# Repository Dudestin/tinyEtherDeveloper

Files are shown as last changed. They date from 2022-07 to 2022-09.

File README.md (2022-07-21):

View this project on [CADLAB.io](https://cadlab.io/project/25780). 
Contact : [@mozc_channel](https://twitter.com/mozc_channel)

# [WIP]tinyEtherDeveloper
Inexpensive FPGA board-based Ethernet evaluation board project.  
Consists mostly of DIP components and uses Tang PriMER. It can be built for about only $50.

## About
**7,000円程度**でほとんどの部品が秋葉原で揃う, Ethernetポートを**4つ**備えた実験ボードです. 10BASE-Tに対応しています.  
はんだ付けが苦手な方でも容易に実装できるよう, 極力面実装部品の仕様は控えています.  
FPGAボードには, SipeedのTang PriMERを用いており, そこそこ豊富なBRAMを備えるため, 様々な応用が可能です.

| Overview | Overview2 | PCB Layout |
| --- | --- |  --- |
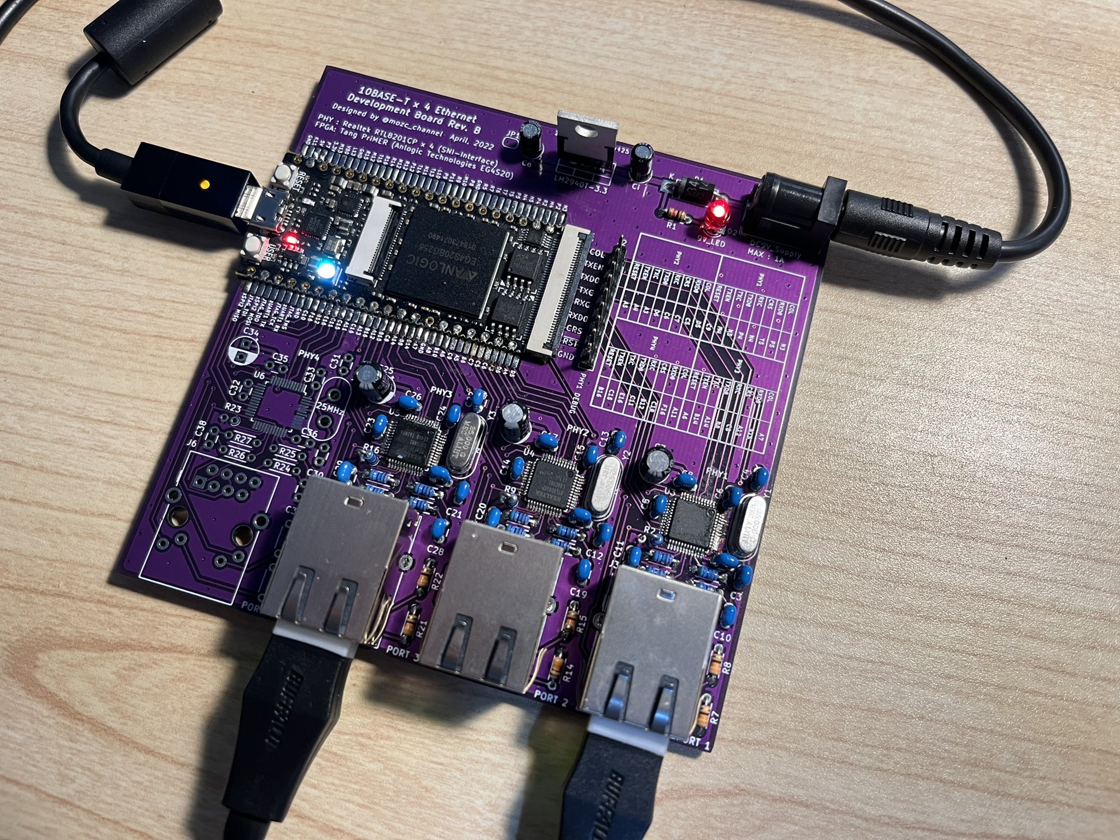
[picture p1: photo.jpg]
assembleBoard
|  |  | |
## Usages and Applications
- Repeater Hub
- Video Broadcasting (Use with MIPI Camera)
- NTP Server
- L2 Switch
- L3 Switch
- Hardware VPN router

## Where to get parts
[部品表](https://partscabi.net/list/92284b79-cc50-4855-a5a0-e0b6e620e11a), [RTL8201CP](https://jp.rs-online.com/web/p/ethernet-interface-ics/0419952) (PHYチップ)

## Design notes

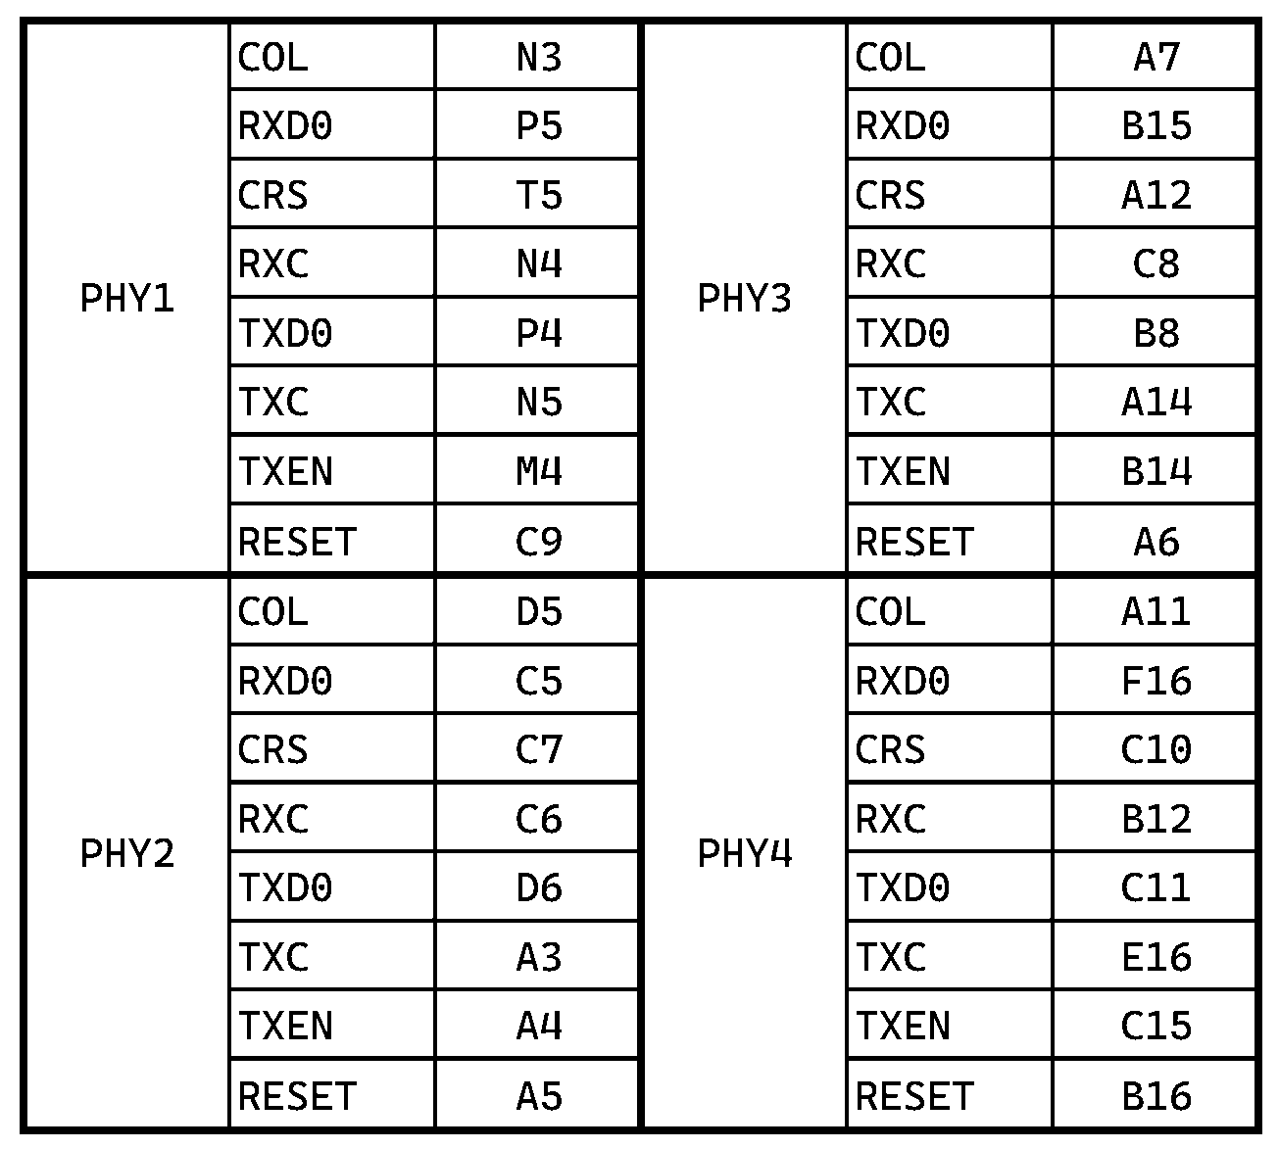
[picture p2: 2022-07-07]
PCB_project/pico_router/table.bmp

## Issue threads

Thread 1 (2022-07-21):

MACスイッチ (L2スイッチ) の実装案

Dudestin, 2022-07-21:
### 状態遷移図
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
#### `AWAIT`と`DESTROY`をどう使い分けるか
- マクロで`AWAIT`と`DESTROY`どちらをそれぞれの転送モードで有効にするか設定できるように.

Dudestin, 2022-07-21:
`MULTICAST`状態は不要
フラッディングさせよう

Dudestin, 2022-07-22:
`BROADCAST`状態も不要.
`UNICAST`状態も削除し`TX`状態とマージ.

Dudestin, 2022-07-22:
`DESTROY`状態も不要.
出力fifo設定信号になにも出力しなければよいだけ.

Dudestin, 2022-07-22:
`WAIT`は実装せず, 溢れたら破棄

Closed 2022-07-23.

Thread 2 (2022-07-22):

MACテーブルの実装方法

Dudestin, 2022-07-22:
## テーブル実装手法
CAM (Contents Associated Memory) を用いる. `data`に対応する`addr`を索引することができるが, `addr->data`が多対1の場合はそのままでは実装できない. したがって, 次のようにaddrを構成し多対1の索引を実現する.
```verilog
addr = {counter, PORT};
```
ここで, `counter`はポート毎に用意され, 新規MACが来る度にインクリメントされる. `PORT`はポート番号.
索引する際は`addr`の下位ビットをスライスすることでポート番号を特定する.
あるポートのMACテーブルがいっぱいの状態で新しいMACアドレスを挿入する際, `counter`のオーバーフローにより自動的に最古のデータが置き換わる.
ポート毎にストアできるMACアドレスの数はcounterの表現可能な数値である.
ブロードキャストアドレスはロジックで判別させる.
### CAMの仕様
`addr`のbit幅 : 5 (ポート毎に8つのMACアドレスを記憶可能)
2^5=32bit幅のメモリを要求する. 現実的なラインは6までか.

### MACテーブルのCAMを用いた実装の例.
| `addr` | `data` | 備考 |
| - | - | - |
| `{3'bxxx, 2'b00}` | `FF:FF:FF:FF:FF:FF` | ブロードキャストアドレス, ロジックで判別 |
| `{3'bxxx, 2'b01}` | `FF:FF:FF:FF:FF:FF` | ブロードキャストアドレス, ロジックで判別 |
| `{3'bxxx, 2'b10}` | `FF:FF:FF:FF:FF:FF` | ブロードキャストアドレス, ロジックで判別 |
| `{3'bxxx, 2'b11}` | `FF:FF:FF:FF:FF:FF` | ブロードキャストアドレス, ロジックで判別 |
| `{3'b000, 2'b01}` | `0A:F4:C2:72:11:2A` | デバイスA, ポート1の先に存在 |
| `{3'b001, 2'b01}` | `BC:5F:F4:F9:7E:7D`  | デバイスB, ポート1の先に存在|
| `{3'b000, 2'b10}` | `1A:CC:3A:66:9A:11`  | デバイスB, ポート1の先に存在|

Dudestin, 2022-07-22:
一定時間でリセットするようにしておく.

Dudestin, 2022-07-22:
`FF:FF:FF:FF:FF:FF`はそもそも`SRC_MAC`に入ることはない.
よって特別な処理はいらず, 通常のフラッディング処理を用いればよい.

Closed 2022-07-23.

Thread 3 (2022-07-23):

BRAM実装CAMメモリのの移植

Dudestin, 2022-07-23:
### `cam_bram.v`の移植
#### 仕様
- 入出力
```Verilog
module ram_dp #
(
    parameter DATA_WIDTH = 32,
    parameter ADDR_WIDTH = 10
)
(
    // port A
    input  wire                    a_clk,
    input  wire                    a_we,
    input  wire [ADDR_WIDTH-1:0]   a_addr,
    input  wire [DATA_WIDTH-1:0]   a_din,
    output wire [DATA_WIDTH-1:0]   a_dout,

    // port B
    input  wire                    b_clk,
    input  wire                    b_we,
    input  wire [ADDR_WIDTH-1:0]   b_addr,
    input  wire [DATA_WIDTH-1:0]   b_din,
    output wire [DATA_WIDTH-1:0]   b_dout
);
```
- BRAM9kbを使用する
- portA,B ともに書き込み時, そのポートの出力には書き込みデータが出力される.
```Verilog
// port A
always @(posedge a_clk) begin
    a_dout_reg <= mem[a_addr];
    if (a_we) begin
        mem[a_addr] <= a_din;
        a_dout_reg <= a_din;
    end
end
```

Closed 2022-07-23.

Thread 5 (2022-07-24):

PHYのFull/Half-Duplexを何かしらの方法で設定する方法の検討

Dudestin, 2022-07-24:
現段階では, Half-Duplex固定.
Full-Duplexを設定できるようになれば, バッファの溢れをリスクを大幅に低減できる.

Dudestin, 2022-07-24:
PHY-ICの都合上, SNI使用時はオートネゴシエーションを使用できず.
ユーザがFull-Duplexを指定できる機構が欲しい. その場合, それぞれのポートの相手側の機器でもマニュアルで10BASE-T/Full-Duplexを指定する必要あり.

Dudestin, 2022-07-29:
FPGAから設定できるように変更することで対応

Closed 2022-07-29.

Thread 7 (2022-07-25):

BRAM32kを使用するFIFOモジュールの作成

Dudestin, 2022-07-25:
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
現在，`BRAM9k`のみを用いてFIFOを実装している．さらに深さを拡張するために`BRAM32k`をインスタンシエーションするFIFOモジュールを自作したい.
また，BRAMの個数を任意にパラメータとして与え，所望するFIFOを生成するモジュールも作りたい． `BRAM9k`, `BRAM32k`を混在できれば文句なし.
なお，STPを実装するためのプロセッサコアに必要なだけのある程度のBRAMは残しておきたい.

Closed 2022-07-27.

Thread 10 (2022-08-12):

PHY-FIFOのCPU, Switch間での排他制御機構

Dudestin, 2022-08-12:
Q：mutexを待機した後獲得して, その後afullだった場合, 待った時間無駄では？
A: CPUは64Byteしか送らないし，そんなに長く待つことはない...

Q: CPUがフレーム送りまくった場合, SWITCH側が送れなくなり不利では ?
   afullの状態でSWITCHがmutex獲得 -> afullで送れないからmutex放棄 -> CPUがmutex獲得 -> afullにの悪しき循環？
   CPUに自重させる以外の方法ある？
A: わからん,,,難しそう......

Q: CPUの送るフレームは破棄されないようにすることは可能?
A: 先にafullを読み, その後mutex獲得すれば(打算的獲得)いける.

Q: mutex獲得の前にafull読んでたらスタベーション起きない? SWITCHの優先度はCPUより低く, 毎回afullがdeassertされる際にmutex獲得勝負で負けちゃうよ.
A: SWITCHはafull読まずmutex獲得 (無策獲得) し，気ままに破棄したりする?

Q: CPUは64Byteしか送らないけど, 1500フルフレーム分 (afullの境界) のスペースを待つ必要ある?
A: ないね, 専用のafullが欲しいね.

Q: やっぱりSWITCH側がスタベーションに陥らない?
A: CPUが送りすぎた場合, 根本的に起こりうる. 自重させる(ソフトウェア)か別の対策(ハードウェアによるmutexの改修)が必要.

Q: ソフトウェアによる対策は？
A: 何万サイクルに一度だけ送出できるようにしたりだとか...

Q: ハードウェアによる対策って具体的には?
A: ＣＰＵがフレームを送出するタイミングに条件を付ける.
   1500(SWITCHが送りうるサイズ) + 64(これから自分が送るやつ)以上の空きがFIFOにあることを条件にmutex獲得?
   ＳＷＩＴＣＨも最低1回は送れる.

Q: それだと逆にCPUが一向に送出できない場合が起こりうるのでは?
A: うん, SWITCHがmutex確保しっぱなしって場合もアップリンクの速度等によっては考えられる.やっぱりだめだね.

結論: 64Byteの空きができ次第, CPUはFIFOにプッシュ. ハードウェアタイマでmutex獲得間隔を設けて自重させることでSWITCHのスタベーションを抑えよう.
      これならCPUが送出するフレームのレイテンシも抑えることができる.

Dudestin, 2022-08-23:
mutexモジュールを作成しMAC_SWITCH, CTRL_FRAME_ISSUERを対応させた

Closed 2022-08-23.

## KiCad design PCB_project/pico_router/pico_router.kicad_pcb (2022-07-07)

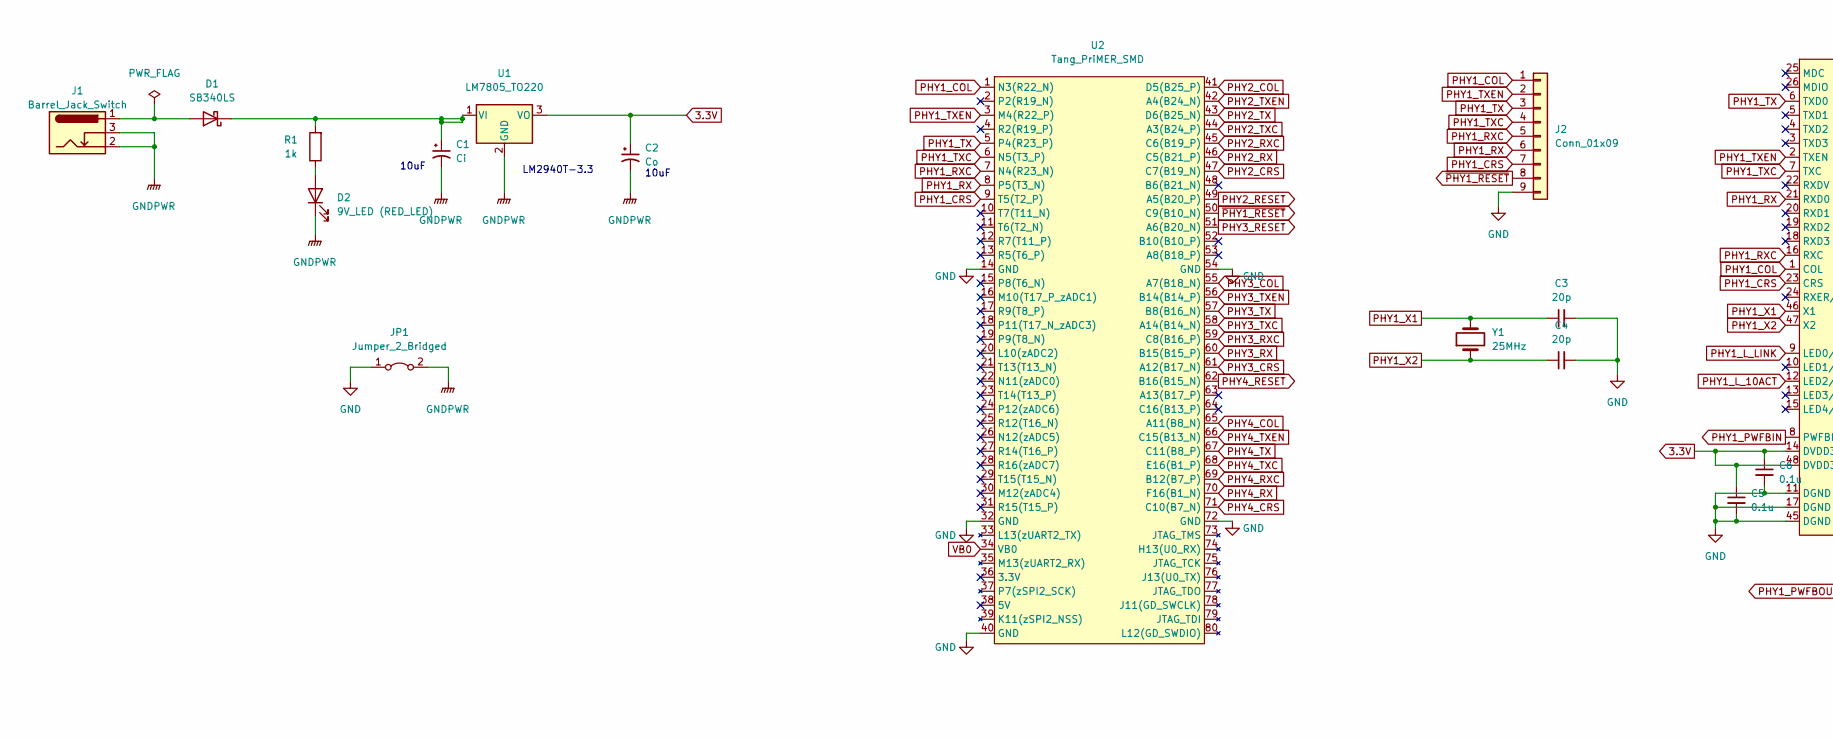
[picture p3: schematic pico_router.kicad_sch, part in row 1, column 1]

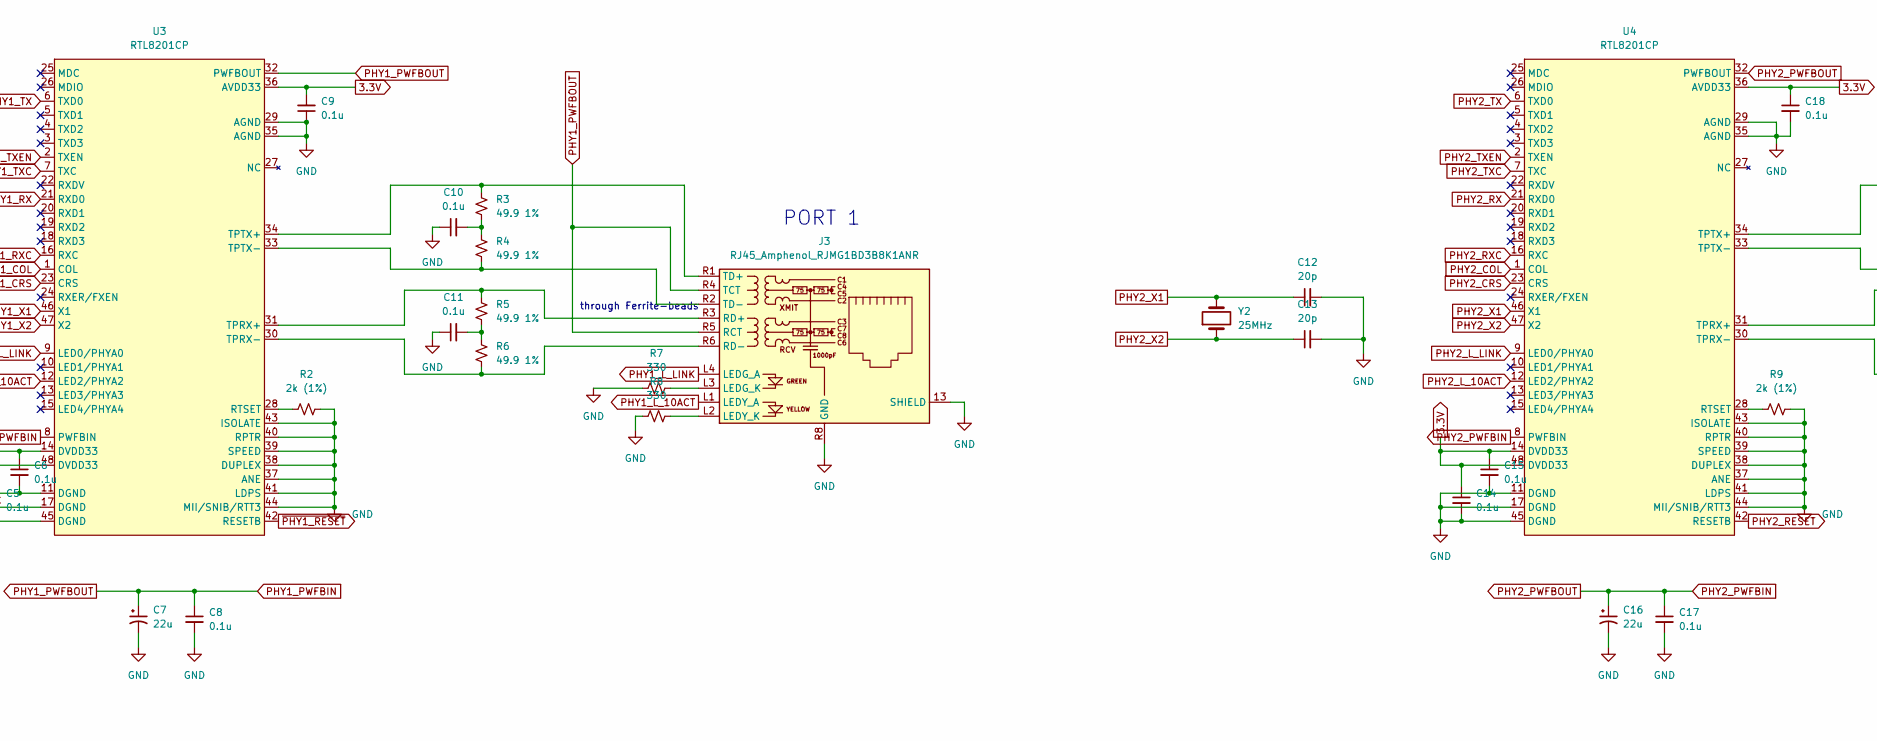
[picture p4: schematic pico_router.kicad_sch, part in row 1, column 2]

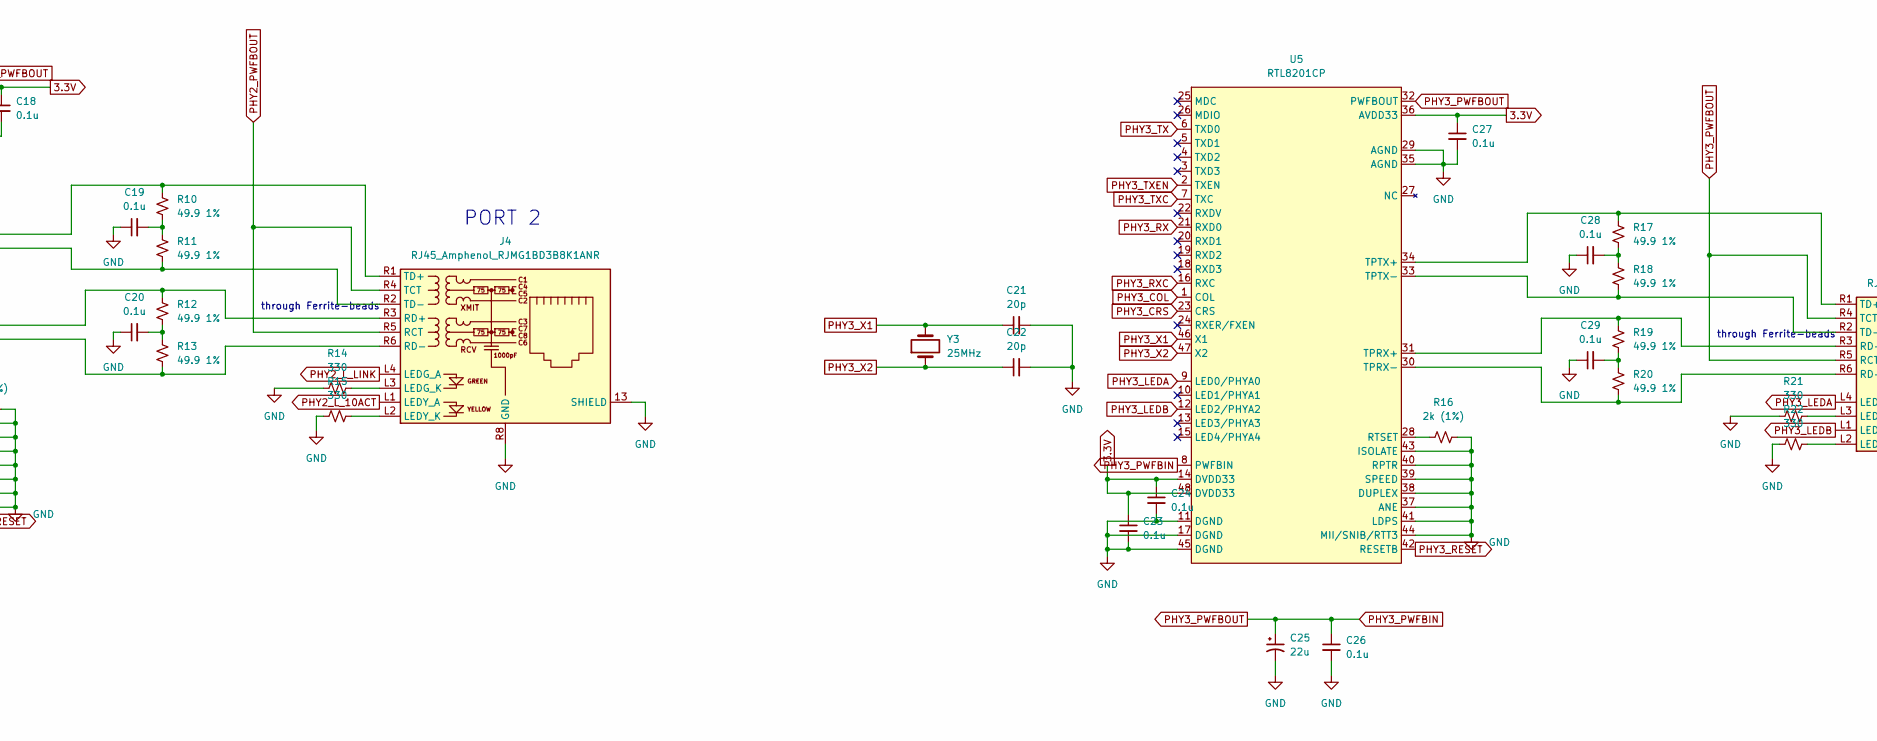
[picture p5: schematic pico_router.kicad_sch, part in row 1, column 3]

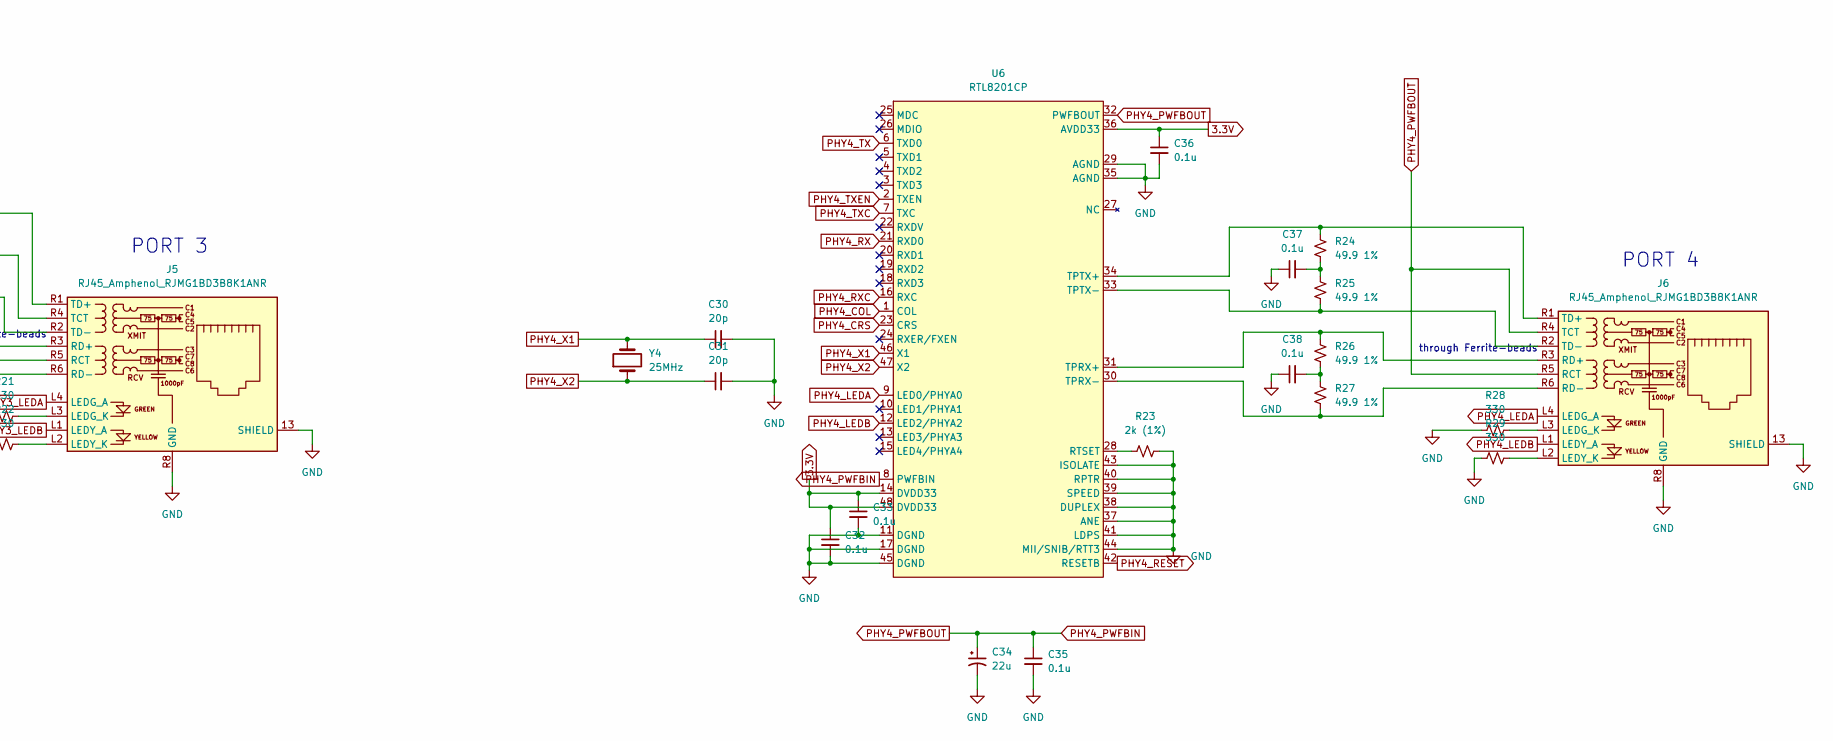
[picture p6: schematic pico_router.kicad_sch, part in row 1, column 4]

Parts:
C1: Ci; CP_Radial_D4.0mm_P2.00mm
C2: Co; CP_Radial_D4.0mm_P2.00mm
C3, C4, C12, C13, C21, C22, C30, C31: 20p; C_Disc_D3.0mm_W1.6mm_P2.50mm
C5, C6, C8, C9, C10, C11, C14, C15, C17, C18, C19, C20, C23, C24, C26, C27, C28, C29, C32, C33, C35, C36, C37, C38: 0.1u; C_Disc_D3.0mm_W1.6mm_P2.50mm
C7, C16, C25, C34: 22u; CP_Radial_D5.0mm_P2.50mm
D1: SB340LS; D_DO-15_P10.16mm_Horizontal
D2: 9V_LED (RED_LED); LED_D3.0mm
J1: Barrel_Jack_Switch; BarrelJack_GCT_DCJ200-10-A_Horizontal
J2: Conn_01x09; PinHeader_1x09_P2.54mm_Vertical
J3, J4, J5, J6: RJ45_Amphenol_RJMG1BD3B8K1ANR
JP1: Jumper_2_Bridged; SolderJumper-2_P1.3mm_Bridged2Bar_RoundedPad1.0x1.5mm
R1: 1k; R_Axial_DIN0204_L3.6mm_D1.6mm_P5.08mm_Horizontal
R2, R9, R16, R23: 2k (1%); R_Axial_DIN0204_L3.6mm_D1.6mm_P1.90mm_Vertical
R3, R4, R5, R6, R10, R11, R12, R13, R17, R18, R19, R20, R24, R25, R26, R27: 49.9 1%; R_Axial_DIN0204_L3.6mm_D1.6mm_P5.08mm_Horizontal
R7, R8, R14, R15, R21, R22, R28, R29: 330; R_Axial_DIN0204_L3.6mm_D1.6mm_P5.08mm_Horizontal
U1: LM7805_TO220; TO-220-3_Vertical
U2: Tang_PriMER_SMD
U3, U4, U5, U6: RTL8201CP; LQFP-48_7x7mm_P0.5mm
Y1, Y2, Y3, Y4: 25MHz; Crystal_HC50_Vertical

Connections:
3.3V: C2.1, C5.1, C6.1, C9.2, C14.1, C15.1, C18.1, C23.1, C24.1, C27.1, C32.1, C33.1, C36.1, U1.3 (VO), U3.14 (DVDD33), U3.36 (AVDD33), U3.48 (DVDD33), U4.14 (DVDD33), U4.36 (AVDD33), U4.48 (DVDD33), U5.14 (DVDD33), U5.36 (AVDD33), U5.48 (DVDD33), U6.14 (DVDD33), U6.36 (AVDD33), U6.48 (DVDD33)
GND: C3.2, C4.2, C5.2, C6.2, C7.2, C8.2, C9.1, C10.1, C11.1, C12.2, C13.2, C14.2, C15.2, C16.2, C17.2, C18.2, C19.1, C20.1, C21.2, C22.2, C23.2, C24.2, C25.2, C26.2, C27.2, C28.1, C29.1, C30.2, C31.2, C32.2, C33.2, C34.2, C35.2, C36.2, C37.1, C38.1, J2.9, J3.13 (SHIELD), J3.R8 (GND), J4.13 (SHIELD), J4.R8 (GND), J5.13 (SHIELD), J5.R8 (GND), J6.13 (SHIELD), J6.R8 (GND), JP1.1 (A), R2.2, R7.1, R8.1, R9.2, R14.1, R15.1, R16.2, R21.1, R22.1, R23.2, R28.1, R29.1, U2.14 (GND), U2.32 (GND), U2.40 (GND), U2.54 (GND), U2.72 (GND), U3.11 (DGND), U3.17 (DGND), U3.29 (AGND), U3.35 (AGND), U3.37 (ANE), U3.38 (DUPLEX), U3.39 (SPEED), U3.40 (RPTR), U3.41 (LDPS), U3.43 (ISOLATE), U3.44 (MII/SNIB/RTT3), U3.45 (DGND), U4.11 (DGND), U4.17 (DGND), U4.29 (AGND), U4.35 (AGND), U4.37 (ANE), U4.38 (DUPLEX), U4.39 (SPEED), U4.40 (RPTR), U4.41 (LDPS), U4.43 (ISOLATE), U4.44 (MII/SNIB/RTT3), U4.45 (DGND), U5.11 (DGND), U5.17 (DGND), U5.29 (AGND), U5.35 (AGND), U5.37 (ANE), U5.38 (DUPLEX), U5.39 (SPEED), U5.40 (RPTR), U5.41 (LDPS), U5.43 (ISOLATE), U5.44 (MII/SNIB/RTT3), U5.45 (DGND), U6.11 (DGND), U6.17 (DGND), U6.29 (AGND), U6.35 (AGND), U6.37 (ANE), U6.38 (DUPLEX), U6.39 (SPEED), U6.40 (RPTR), U6.41 (LDPS), U6.43 (ISOLATE), U6.44 (MII/SNIB/RTT3), U6.45 (DGND)
GNDPWR: C1.2, C2.2, D2.1 (K), J1.2, J1.3, JP1.2 (B), U1.2 (GND)
unnamed: C1.1, D1.1 (K), R1.2, U1.1 (VI)
unnamed: C10.2, R3.2, R4.1
unnamed: C11.2, R5.2, R6.1
unnamed: C19.2, R10.2, R11.1
unnamed: C20.2, R12.2, R13.1
unnamed: C28.2, R17.2, R18.1
unnamed: C29.2, R19.2, R20.1
unnamed: C37.2, R24.2, R25.1
unnamed: C38.2, R26.2, R27.1
unnamed: D1.2 (A), J1.1
unnamed: D2.2 (A), R1.1
unnamed: J3.L2 (LEDY_K), R8.2
unnamed: J3.L3 (LEDG_K), R7.2
unnamed: J3.R1 (TD+), R3.1, U3.34 (TPTX+)
unnamed: J3.R2 (TD-), R4.2, U3.33 (TPTX-)
unnamed: J3.R3 (RD+), R5.1, U3.31 (TPRX+)
unnamed: J3.R6 (RD-), R6.2, U3.30 (TPRX-)
unnamed: J4.L2 (LEDY_K), R15.2
unnamed: J4.L3 (LEDG_K), R14.2
unnamed: J4.R1 (TD+), R10.1, U4.34 (TPTX+)
unnamed: J4.R2 (TD-), R11.2, U4.33 (TPTX-)
unnamed: J4.R3 (RD+), R12.1, U4.31 (TPRX+)
unnamed: J4.R6 (RD-), R13.2, U4.30 (TPRX-)
unnamed: J5.L2 (LEDY_K), R22.2
unnamed: J5.L3 (LEDG_K), R21.2
unnamed: J5.R1 (TD+), R17.1, U5.34 (TPTX+)
unnamed: J5.R2 (TD-), R18.2, U5.33 (TPTX-)
unnamed: J5.R3 (RD+), R19.1, U5.31 (TPRX+)
unnamed: J5.R6 (RD-), R20.2, U5.30 (TPRX-)
unnamed: J6.L2 (LEDY_K), R29.2
unnamed: J6.L3 (LEDG_K), R28.2
unnamed: J6.R1 (TD+), R24.1, U6.34 (TPTX+)
unnamed: J6.R2 (TD-), R25.2, U6.33 (TPTX-)
unnamed: J6.R3 (RD+), R26.1, U6.31 (TPRX+)
unnamed: J6.R6 (RD-), R27.2, U6.30 (TPRX-)
unnamed: R2.1, U3.28 (RTSET)
unnamed: R9.1, U4.28 (RTSET)
unnamed: R16.1, U5.28 (RTSET)
unnamed: R23.1, U6.28 (RTSET)
PHY1_COL: J2.1, U2.1 (N3(R22_N)), U3.1 (COL)
PHY1_CRS: J2.7, U2.9 (T5(T2_P)), U3.23 (CRS)
PHY1_L_10ACT: J3.L1 (LEDY_A), U3.12 (LED2/PHYA2)
PHY1_L_LINK: J3.L4 (LEDG_A), U3.9 (LED0/PHYA0)
PHY1_PWFBIN: C7.1, C8.1, J3.R4 (TCT), J3.R5 (RCT), U3.8 (PWFBIN), U3.32 (PWFBOUT)
PHY1_RX: J2.6, U2.8 (P5(T3_N)), U3.21 (RXD0)
PHY1_RXC: J2.5, U2.7 (N4(R23_N)), U3.16 (RXC)
PHY1_TX: J2.3, U2.5 (P4(R23_P)), U3.6 (TXD0)
PHY1_TXC: J2.4, U2.6 (N5(T3_P)), U3.7 (TXC)
PHY1_TXEN: J2.2, U2.3 (M4(R22_P)), U3.2 (TXEN)
PHY1_X1: C3.1, U3.46 (X1), Y1.2
PHY1_X2: C4.1, U3.47 (X2), Y1.1
PHY2_COL: U2.41 (D5(B25_P)), U4.1 (COL)
PHY2_CRS: U2.47 (C7(B19_N)), U4.23 (CRS)
PHY2_L_10ACT: J4.L1 (LEDY_A), U4.12 (LED2/PHYA2)
PHY2_L_LINK: J4.L4 (LEDG_A), U4.9 (LED0/PHYA0)
PHY2_PWFBIN: C16.1, C17.1, J4.R4 (TCT), J4.R5 (RCT), U4.8 (PWFBIN), U4.32 (PWFBOUT)
PHY2_RESET: U2.49 (A5(B20_P)), U4.42 (RESETB)
PHY2_RX: U2.46 (C5(B21_P)), U4.21 (RXD0)
PHY2_RXC: U2.45 (C6(B19_P)), U4.16 (RXC)
PHY2_TX: U2.43 (D6(B25_N)), U4.6 (TXD0)
PHY2_TXC: U2.44 (A3(B24_P)), U4.7 (TXC)
PHY2_TXEN: U2.42 (A4(B24_N)), U4.2 (TXEN)
PHY2_X1: C12.1, U4.46 (X1), Y2.2
PHY2_X2: C13.1, U4.47 (X2), Y2.1
PHY3_COL: U2.55 (A7(B18_N)), U5.1 (COL)
PHY3_CRS: U2.61 (A12(B17_N)), U5.23 (CRS)
PHY3_LEDA: J5.L4 (LEDG_A), U5.9 (LED0/PHYA0)
PHY3_LEDB: J5.L1 (LEDY_A), U5.12 (LED2/PHYA2)
PHY3_PWFBIN: C25.1, C26.1, J5.R4 (TCT), J5.R5 (RCT), U5.8 (PWFBIN), U5.32 (PWFBOUT)
PHY3_RESET: U2.51 (A6(B20_N)), U5.42 (RESETB)
PHY3_RX: U2.60 (B15(B15_P)), U5.21 (RXD0)
PHY3_RXC: U2.59 (C8(B16_P)), U5.16 (RXC)
PHY3_TX: U2.57 (B8(B16_N)), U5.6 (TXD0)
PHY3_TXC: U2.58 (A14(B14_N)), U5.7 (TXC)
PHY3_TXEN: U2.56 (B14(B14_P)), U5.2 (TXEN)
PHY3_X1: C21.1, U5.46 (X1), Y3.2
PHY3_X2: C22.1, U5.47 (X2), Y3.1
PHY4_COL: U2.65 (A11(B8_N)), U6.1 (COL)
PHY4_CRS: U2.71 (C10(B7_N)), U6.23 (CRS)
PHY4_LEDA: J6.L4 (LEDG_A), U6.9 (LED0/PHYA0)
PHY4_LEDB: J6.L1 (LEDY_A), U6.12 (LED2/PHYA2)
PHY4_PWFBIN: C34.1, C35.1, J6.R4 (TCT), J6.R5 (RCT), U6.8 (PWFBIN), U6.32 (PWFBOUT)
PHY4_RESET: U2.62 (B16(B15_N)), U6.42 (RESETB)
PHY4_RX: U2.70 (F16(B1_N)), U6.21 (RXD0)
PHY4_RXC: U2.69 (B12(B7_P)), U6.16 (RXC)
PHY4_TX: U2.67 (C11(B8_P)), U6.6 (TXD0)
PHY4_TXC: U2.68 (E16(B1_P)), U6.7 (TXC)
PHY4_TXEN: U2.66 (C15(B13_N)), U6.2 (TXEN)
PHY4_X1: C30.1, U6.46 (X1), Y4.2
PHY4_X2: C31.1, U6.47 (X2), Y4.1
VB0: U2.34 (VB0)
~PHY1_RESET: J2.8, U2.50 (C9(B10_N)), U3.42 (RESETB)

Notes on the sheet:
PORT 2
LM2940T-3.3
PORT 4
through Ferrite-beads
PORT 1
10uF
PORT 3

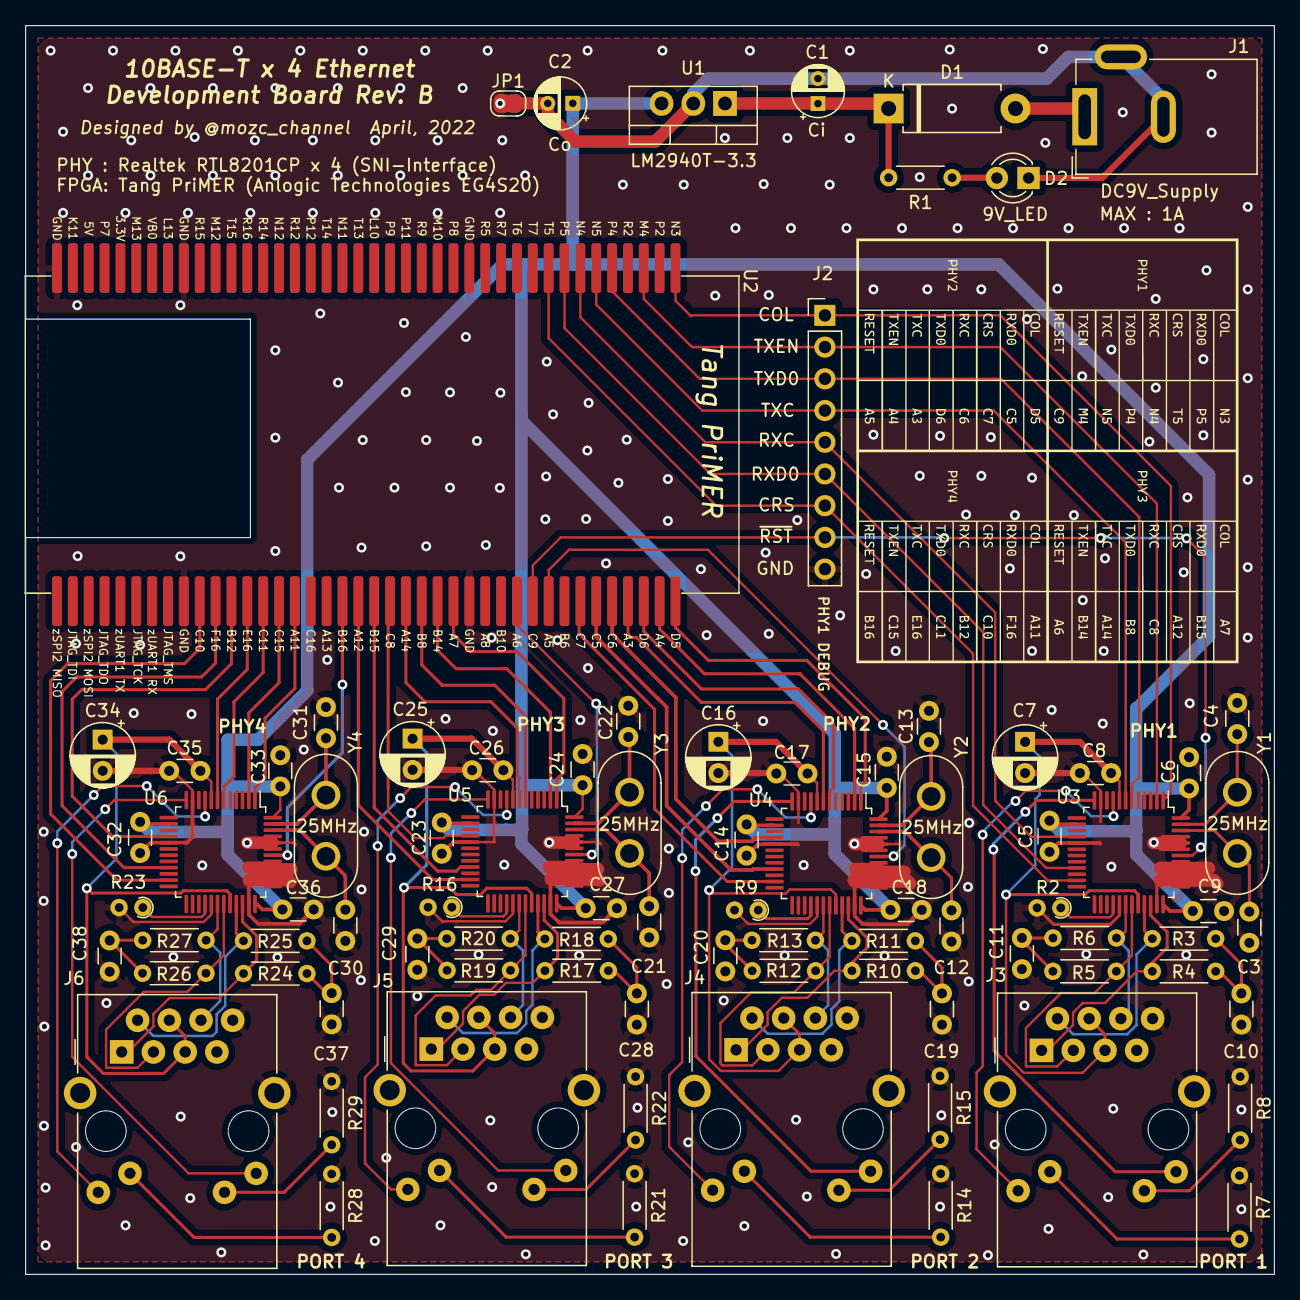
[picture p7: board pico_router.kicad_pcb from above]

Board: 2 copper layers, 100.0 x 100.0 mm, 86 parts (0 on the bottom side), 94 nets.

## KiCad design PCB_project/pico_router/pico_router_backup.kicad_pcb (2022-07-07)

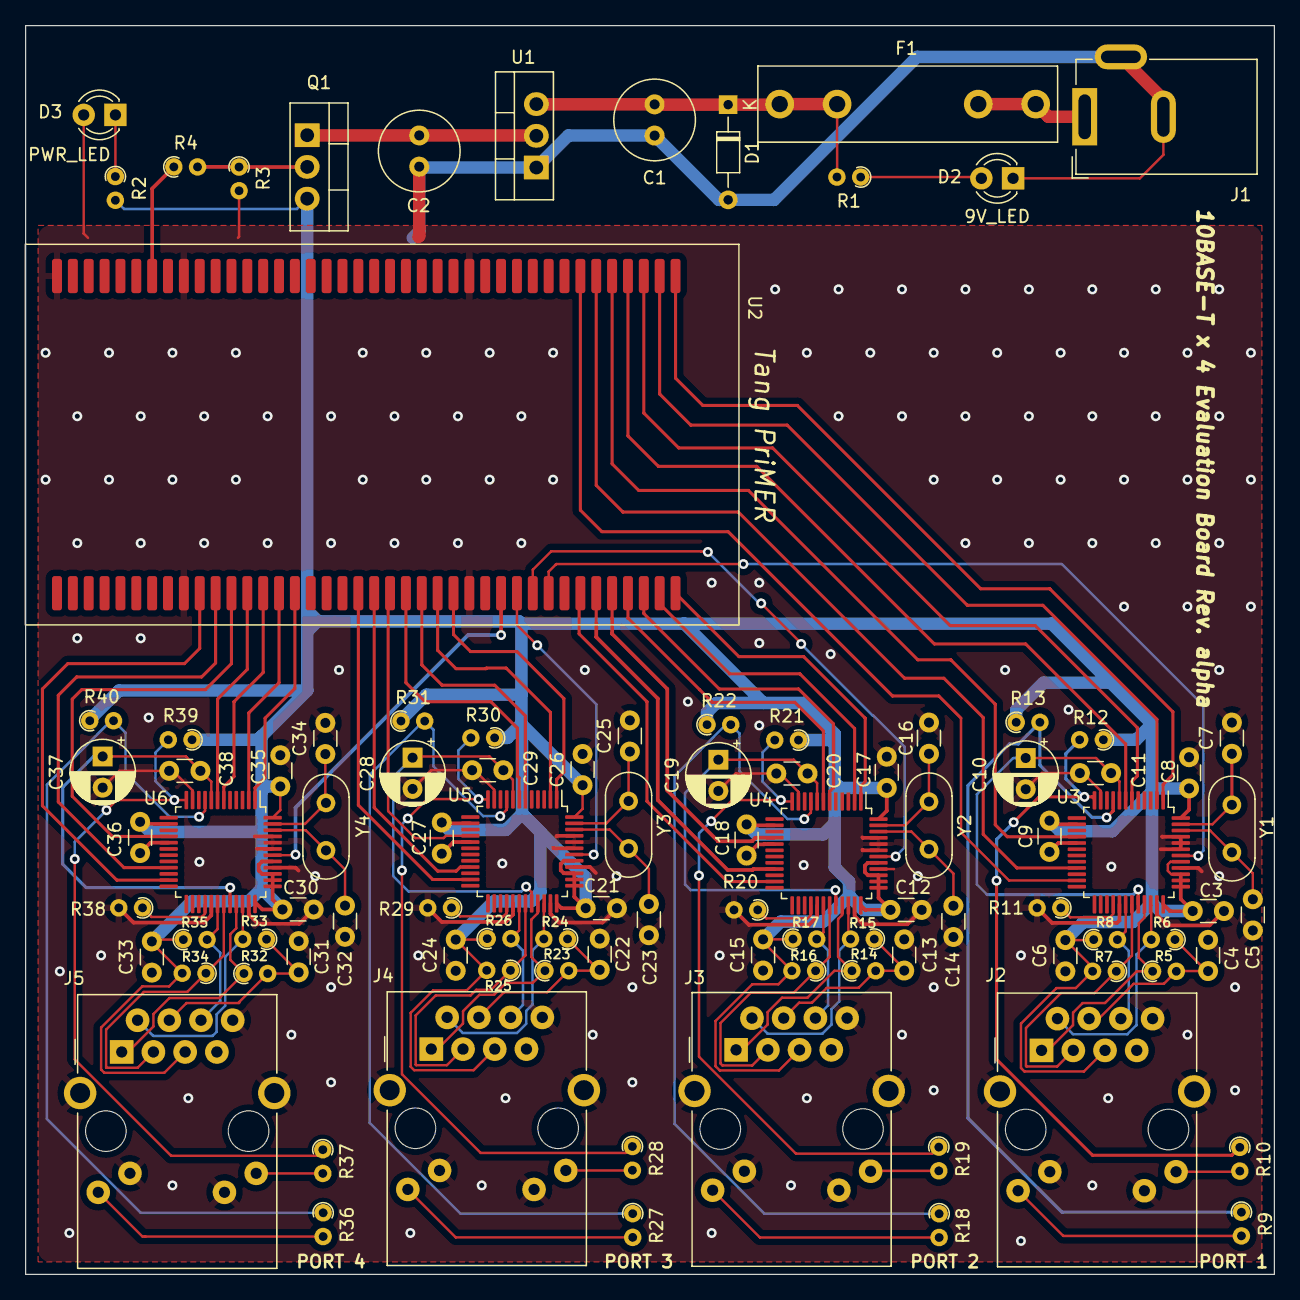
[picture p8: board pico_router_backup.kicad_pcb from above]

Board: 2 copper layers, 100.0 x 100.0 mm, 98 parts (0 on the bottom side), 93 nets.

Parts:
C1: Ci; C_Radial_D6.3mm_H11.0mm_P2.50mm
C2: Co; C_Radial_D6.3mm_H11.0mm_P2.50mm
C3, C4, C6, C8, C9, C11, C12, C13, C15, C17, C18, C20, C21, C22, C24, C26, C27, C29, C30, C31, C33, C35, C36, C38: 0.1u; C_Disc_D3.0mm_W1.6mm_P2.50mm
C5, C7, C14, C16, C23, C25, C32, C34: 20p; C_Disc_D3.0mm_W1.6mm_P2.50mm
C10, C19, C28, C37: 22u; CP_Radial_D5.0mm_P2.50mm
D1: 9.1V; D_DO-34_SOD68_P7.62mm_Horizontal
D2: 9V_LED (RED_LED); LED_D3.0mm
D3: PWR_LED (BLUE); LED_D3.0mm
F1: 1A; Fuseholder_Littelfuse_100_series_5x20mm
J1: Barrel_Jack_Switch; BarrelJack_GCT_DCJ200-10-A_Horizontal
J2, J3, J4, J5: RJ45_Amphenol_RJMG1BD3B8K1ANR
Q1: 2SK4017; TO-220-3_Vertical
R1: 1k; R_Axial_DIN0204_L3.6mm_D1.6mm_P1.90mm_Vertical
R2, R4, R9, R10, R18, R19, R27, R28, R36, R37: 330; R_Axial_DIN0204_L3.6mm_D1.6mm_P1.90mm_Vertical
R3: 10k; R_Axial_DIN0204_L3.6mm_D1.6mm_P1.90mm_Vertical
R5, R6, R7, R8, R14, R15, R16, R17, R23, R24, R25, R26, R32, R33, R34, R35: 49.9 1%; R_Axial_DIN0204_L3.6mm_D1.6mm_P1.90mm_Vertical
R11, R20, R29, R38: 2k (1%); R_Axial_DIN0204_L3.6mm_D1.6mm_P1.90mm_Vertical
R12, R13, R21, R22, R30, R31, R39, R40: 5.1k; R_Axial_DIN0204_L3.6mm_D1.6mm_P1.90mm_Vertical
U1: LM317_TO-220; TO-220-3_Vertical
U2: Tang_PriMER_SMD
U3, U4, U5, U6: RTL8201CP; LQFP-48_7x7mm_P0.5mm
Y1, Y2, Y3, Y4: 25MHz; Crystal_HC52-6mm_Vertical

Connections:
3.3V: C3.1, C6.2, C8.1, C9.1, C12.1, C15.2, C17.1, C18.1, C21.1, C24.2, C26.1, C27.1, C30.1, C33.2, C35.1, C36.1, J2.R5 (RCT), J3.R5 (RCT), J4.R5 (RCT), J5.R5 (RCT), Q1.3 (S), R2.2, R7.2, R8.1, R12.1, R13.1, R16.2, R17.1, R21.1, R22.1, R25.2, R26.1, R30.1, R31.1, R34.2, R35.1, R39.1, R40.1, U3.14 (DVDD33), U3.36 (AVDD33), U3.37 (ANE), U3.38 (DUPLEX), U3.39 (SPEED), U3.41 (LDPS), U3.48 (DVDD33), U4.14 (DVDD33), U4.36 (AVDD33), U4.37 (ANE), U4.38 (DUPLEX), U4.39 (SPEED), U4.41 (LDPS), U4.48 (DVDD33), U5.14 (DVDD33), U5.36 (AVDD33), U5.37 (ANE), U5.38 (DUPLEX), U5.39 (SPEED), U5.41 (LDPS), U5.48 (DVDD33), U6.14 (DVDD33), U6.36 (AVDD33), U6.37 (ANE), U6.38 (DUPLEX), U6.39 (SPEED), U6.41 (LDPS), U6.48 (DVDD33)
DC_OUT: C2.1, Q1.1 (D), U1.2 (VO)
GND: C1.2, C2.2, C3.2, C4.1, C5.2, C6.1, C7.2, C8.2, C9.2, C10.2, C11.2, C12.2, C13.1, C14.2, C15.1, C16.2, C17.2, C18.2, C19.2, C20.2, C21.2, C22.1, C23.2, C24.1, C25.2, C26.2, C27.2, C28.2, C29.2, C30.2, C31.1, C32.2, C33.1, C34.2, C35.2, C36.2, C37.2, C38.2, D1.2 (A), D2.1 (K), D3.2 (A), J1.2, J1.3, J2.13 (SHIELD), J2.L2 (LEDY_K), J2.L3 (LEDG_K), J2.R8 (GND), J3.13 (SHIELD), J3.L2 (LEDY_K), J3.L3 (LEDG_K), J3.R8 (GND), J4.13 (SHIELD), J4.L2 (LEDY_K), J4.L3 (LEDG_K), J4.R8 (GND), J5.13 (SHIELD), J5.L2 (LEDY_K), J5.L3 (LEDG_K), J5.R8 (GND), R3.2, R11.2, R20.2, R29.2, R38.2, U1.1 (ADJ), U2.14 (GND), U2.32 (GND), U2.40 (GND), U2.54 (GND), U2.72 (GND), U3.11 (DGND), U3.17 (DGND), U3.29 (AGND), U3.35 (AGND), U3.40 (RPTR), U3.43 (ISOLATE), U3.44 (MII/SNIB/RTT3), U3.45 (DGND), U4.11 (DGND), U4.17 (DGND), U4.29 (AGND), U4.35 (AGND), U4.40 (RPTR), U4.43 (ISOLATE), U4.44 (MII/SNIB/RTT3), U4.45 (DGND), U5.11 (DGND), U5.17 (DGND), U5.29 (AGND), U5.35 (AGND), U5.40 (RPTR), U5.43 (ISOLATE), U5.44 (MII/SNIB/RTT3), U5.45 (DGND), U6.11 (DGND), U6.17 (DGND), U6.29 (AGND), U6.35 (AGND), U6.40 (RPTR), U6.43 (ISOLATE), U6.44 (MII/SNIB/RTT3), U6.45 (DGND)
unnamed: C1.1, D1.1 (K), F1.1, R1.2, U1.3 (VI)
unnamed: C4.2, J2.R4 (TCT), R5.2, R6.1
unnamed: C13.2, J3.R4 (TCT), R14.2, R15.1
unnamed: C22.2, J4.R4 (TCT), R23.2, R24.1
unnamed: C31.2, J5.R4 (TCT), R32.2, R33.1
unnamed: D2.2 (A), R1.1
unnamed: D3.1 (K), R2.1
unnamed: F1.2, J1.1
unnamed: J2.L1 (LEDY_A), R10.2
unnamed: J2.L4 (LEDG_A), R9.2
unnamed: J2.R1 (TD+), R5.1, U3.33 (TPTX+)
unnamed: J2.R2 (TD-), R6.2, U3.34 (TPTX-)
unnamed: J2.R3 (RD+), R7.1, U3.31 (TPRX+)
unnamed: J2.R6 (RD-), R8.2, U3.30 (TPRX-)
unnamed: J3.L1 (LEDY_A), R19.2
unnamed: J3.L4 (LEDG_A), R18.2
unnamed: J3.R1 (TD+), R14.1, U4.33 (TPTX+)
unnamed: J3.R2 (TD-), R15.2, U4.34 (TPTX-)
unnamed: J3.R3 (RD+), R16.1, U4.31 (TPRX+)
unnamed: J3.R6 (RD-), R17.2, U4.30 (TPRX-)
unnamed: J4.L1 (LEDY_A), R28.2
unnamed: J4.L4 (LEDG_A), R27.2
unnamed: J4.R1 (TD+), R23.1, U5.33 (TPTX+)
unnamed: J4.R2 (TD-), R24.2, U5.34 (TPTX-)
unnamed: J4.R3 (RD+), R25.1, U5.31 (TPRX+)
unnamed: J4.R6 (RD-), R26.2, U5.30 (TPRX-)
unnamed: J5.L1 (LEDY_A), R37.2
unnamed: J5.L4 (LEDG_A), R36.2
unnamed: J5.R1 (TD+), R32.1, U6.33 (TPTX+)
unnamed: J5.R2 (TD-), R33.2, U6.34 (TPTX-)
unnamed: J5.R3 (RD+), R34.1, U6.31 (TPRX+)
unnamed: J5.R6 (RD-), R35.2, U6.30 (TPRX-)
unnamed: Q1.2 (G), R3.1, R4.2
unnamed: R11.1, U3.28 (RTSET)
unnamed: R20.1, U4.28 (RTSET)
unnamed: R29.1, U5.28 (RTSET)
unnamed: R38.1, U6.28 (RTSET)
PHY1_COL: U2.1 (N3(R22_N)), U3.1 (COL)
PHY1_CRS: U2.7 (N4(R23_N)), U3.23 (CRS)
PHY1_LEDA: R9.1, R13.2, U3.9 (LED0/PHYA0)
PHY1_LEDB: R10.1, R12.2, U3.12 (LED2/PHYA2)
PHY1_PWFBIN: C10.1, C11.1, U3.8 (PWFBIN), U3.32 (PWFBOUT)
PHY1_RESET: U2.49 (A5(B20_P)), U3.42 (RESETB)
PHY1_RX: U2.6 (N5(T3_P)), U3.21 (RXD0)
PHY1_RXC: U2.5 (P4(R23_P)), U3.16 (RXC)
PHY1_TX: U2.3 (M4(R22_P)), U3.6 (TXD0)
PHY1_TXC: U2.4 (R2(R19_P)), U3.7 (TXC)
PHY1_TXEN: U2.2 (P2(R19_N)), U3.2 (TXEN)
PHY1_X1: C5.1, U3.46 (X1), Y1.2
PHY1_X2: C7.1, U3.47 (X2), Y1.1
PHY2_COL: U2.41 (D5(B25_P)), U4.1 (COL)
PHY2_CRS: U2.47 (C7(B19_N)), U4.23 (CRS)
PHY2_LEDA: R18.1, R22.2, U4.9 (LED0/PHYA0)
PHY2_LEDB: R19.1, R21.2, U4.12 (LED2/PHYA2)
PHY2_PWFBIN: C19.1, C20.1, U4.8 (PWFBIN), U4.32 (PWFBOUT)
PHY2_RESET: U2.50 (C9(B10_N)), U4.42 (RESETB)
PHY2_RX: U2.46 (C5(B21_P)), U4.21 (RXD0)
PHY2_RXC: U2.45 (C6(B19_P)), U4.16 (RXC)
PHY2_TX: U2.43 (D6(B25_N)), U4.6 (TXD0)
PHY2_TXC: U2.44 (A3(B24_P)), U4.7 (TXC)
PHY2_TXEN: U2.42 (A4(B24_N)), U4.2 (TXEN)
PHY2_X1: C14.1, U4.46 (X1), Y2.2
PHY2_X2: C16.1, U4.47 (X2), Y2.1
PHY3_COL: U2.55 (A7(B18_N)), U5.1 (COL)
PHY3_CRS: U2.61 (A12(B17_N)), U5.23 (CRS)
PHY3_LEDA: R27.1, R31.2, U5.9 (LED0/PHYA0)
PHY3_LEDB: R28.1, R30.2, U5.12 (LED2/PHYA2)
PHY3_PWFBIN: C28.1, C29.1, U5.8 (PWFBIN), U5.32 (PWFBOUT)
PHY3_RESET: U2.51 (A6(B20_N)), U5.42 (RESETB)
PHY3_RX: U2.60 (B15(B15_P)), U5.21 (RXD0)
PHY3_RXC: U2.59 (C8(B16_P)), U5.16 (RXC)
PHY3_TX: U2.57 (B8(B16_N)), U5.6 (TXD0)
PHY3_TXC: U2.58 (A14(B14_N)), U5.7 (TXC)
PHY3_TXEN: U2.56 (B14(B14_P)), U5.2 (TXEN)
PHY3_X1: C23.1, U5.46 (X1), Y3.2
PHY3_X2: C25.1, U5.47 (X2), Y3.1
PHY4_COL: U2.65 (A11(B8_N)), U6.1 (COL)
PHY4_CRS: U2.71 (C10(B7_N)), U6.23 (CRS)
PHY4_LEDA: R36.1, R40.2, U6.9 (LED0/PHYA0)
PHY4_LEDB: R37.1, R39.2, U6.12 (LED2/PHYA2)
PHY4_PWFBIN: C37.1, C38.1, U6.8 (PWFBIN), U6.32 (PWFBOUT)
PHY4_RESET: U2.52 (B10(B10_P)), U6.42 (RESETB)
PHY4_RX: U2.70 (F16(B1_N)), U6.21 (RXD0)
PHY4_RXC: U2.69 (B12(B7_P)), U6.16 (RXC)
PHY4_TX: U2.67 (C11(B8_P)), U6.6 (TXD0)
PHY4_TXC: U2.68 (E16(B1_P)), U6.7 (TXC)
PHY4_TXEN: U2.66 (C15(B13_N)), U6.2 (TXEN)
PHY4_X1: C32.1, U6.46 (X1), Y4.2
PHY4_X2: C34.1, U6.47 (X2), Y4.1
VB0: R4.1, U2.34 (VB0)

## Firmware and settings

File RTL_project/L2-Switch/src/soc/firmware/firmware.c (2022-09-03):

/*
 *  PicoSoC - A simple example SoC using PicoRV32
 *
 *  Copyright (C) 2017  Claire Xenia Wolf <claire@yosyshq.com>
 *
 *  Permission to use, copy, modify, and/or distribute this software for any
 *  purpose with or without fee is hereby granted, provided that the above
 *  copyright notice and this permission notice appear in all copies.
 *
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
 */

#include <stdint.h>
#include <stdbool.h>

#define MEM_TOTAL 16384

// Terminal graphic macro
#define CLS print("\033[2J"); // clear screen
#define RED print("\033[31m");
#define GRN print("\033[32m");
#define YEL print("\033[33m");
#define BLU print("\033[34m");
#define RES_COL print("\033[39m"); // restore color
#define LOC(X, Y) print("\033[ ## X;# ## YH");

// a pointer to this is a null pointer, but the compiler does not
// know that because "sram" is a linker symbol from sections.lds.
extern uint32_t sram;

#define reg_uart_clkdiv (*(volatile uint32_t*)0x02000004)
#define reg_uart_data (*(volatile uint32_t*)0x02000008)

// PHY Stats Memory-mapped Interface
#define reg_phy0_rx_succ_count_gray (*(volatile uint16_t*)0x03000000)
#define reg_phy0_rx_OF_count_gray   (*(volatile uint16_t*)0x03000004)
#define reg_phy0_tx_succ_count_gray (*(volatile uint16_t*)0x03000008)
#define reg_phy0_tx_fail_count_gray (*(volatile uint16_t*)0x0300000C)

#define reg_phy1_rx_succ_count_gray (*(volatile uint16_t*)0x03000100)
#define reg_phy1_rx_OF_count_gray   (*(volatile uint16_t*)0x03000104)
#define reg_phy1_tx_succ_count_gray (*(volatile uint16_t*)0x03000108)
#define reg_phy1_tx_fail_count_gray (*(volatile uint16_t*)0x0300010C)

#define reg_phy2_rx_succ_count_gray (*(volatile uint16_t*)0x03000200)
#define reg_phy2_rx_OF_count_gray   (*(volatile uint16_t*)0x03000204)
#define reg_phy2_tx_succ_count_gray (*(volatile uint16_t*)0x03000208)
#define reg_phy2_tx_fail_count_gray (*(volatile uint16_t*)0x0300020C)

#define reg_phy3_rx_succ_count_gray (*(volatile uint16_t*)0x03000300)
#define reg_phy3_rx_OF_count_gray   (*(volatile uint16_t*)0x03000304)
#define reg_phy3_tx_succ_count_gray (*(volatile uint16_t*)0x03000308)
#define reg_phy3_tx_fail_count_gray (*(volatile uint16_t*)0x0300030C)

#define PHY0_ADDR   (volatile uint16_t*)0x07000000
#define PHY1_ADDR   (volatile uint16_t*)0x07000100
#define PHY2_ADDR   (volatile uint16_t*)0x07000200
#define PHY3_ADDR   (volatile uint16_t*)0x07000300

#define REG0_OFFSET  (0x00000000)
#define REG1_OFFSET  (0x00000004)
#define REG2_OFFSET  (0x00000008)
#define REG3_OFFSET  (0x0000000C)
#define REG4_OFFSET  (0x00000010)
#define REG5_OFFSET  (0x00000014)
#define REG6_OFFSET  (0x00000018)
#define REG7_OFFSET  (0x0000001C)
#define REG8_OFFSET  (0x00000020)
#define REG9_OFFSET  (0x00000024)
#define REG10_OFFSET (0x00000028)
#define REG11_OFFSET (0x0000002C)

#define HOGEFUGA (*(volatile uint16_t*)0x07000008)

// --------------------------------------------------------

void putchar(char c)
{
        if (c == '\n')
                putchar('\r');
        reg_uart_data = c;
}

void print(const char *p)
{
        while (*p)
                putchar(*(p++));
}

void print_hex(uint32_t v, int digits)
{
        for (int i = 7; i >= 0; i--) {
                char c = "0123456789abcdef"[(v >> (4*i)) & 15];
                if (c == '0' && i >= digits) continue;
                putchar(c);
                digits = i;
        }
}

void print_dec(uint32_t v)
{
        if (v >= 1000) {
                print(">=1000");
                return;
        }

        if      (v >= 900) { putchar('9'); v -= 900; }
        else if (v >= 800) { putchar('8'); v -= 800; }
        else if (v >= 700) { putchar('7'); v -= 700; }
        else if (v >= 600) { putchar('6'); v -= 600; }
        else if (v >= 500) { putchar('5'); v -= 500; }
        else if (v >= 400) { putchar('4'); v -= 400; }
        else if (v >= 300) { putchar('3'); v -= 300; }
        else if (v >= 200) { putchar('2'); v -= 200; }
        else if (v >= 100) { putchar('1'); v -= 100; }

        if      (v >= 90) { putchar('9'); v -= 90; }
        else if (v >= 80) { putchar('8'); v -= 80; }
        else if (v >= 70) { putchar('7'); v -= 70; }
        else if (v >= 60) { putchar('6'); v -= 60; }
        else if (v >= 50) { putchar('5'); v -= 50; }
        else if (v >= 40) { putchar('4'); v -= 40; }
        else if (v >= 30) { putchar('3'); v -= 30; }
        else if (v >= 20) { putchar('2'); v -= 20; }
        else if (v >= 10) { putchar('1'); v -= 10; }

        if      (v >= 9) { putchar('9'); v -= 9; }
        else if (v >= 8) { putchar('8'); v -= 8; }
        else if (v >= 7) { putchar('7'); v -= 7; }
        else if (v >= 6) { putchar('6'); v -= 6; }
        else if (v >= 5) { putchar('5'); v -= 5; }
        else if (v >= 4) { putchar('4'); v -= 4; }
        else if (v >= 3) { putchar('3'); v -= 3; }
        else if (v >= 2) { putchar('2'); v -= 2; }
        else if (v >= 1) { putchar('1'); v -= 1; }
        else putchar('0');
}

char getchar_prompt(char *prompt)
{
        int32_t c = -1;

        uint32_t cycles_begin, cycles_now, cycles;
        __asm__ volatile ("rdcycle %0" : "=r"(cycles_begin));

        if (prompt)
                print(prompt);

        while (c == -1) {
                __asm__ volatile ("rdcycle %0" : "=r"(cycles_now));
                cycles = cycles_now - cycles_begin;
                if (cycles > 12000000) {
                        if (prompt)
                                print(prompt);
                        cycles_begin = cycles_now;
                }
                c = reg_uart_data;
        }

        return c;
}

char getchar()
{
        return getchar_prompt(0);
}

uint16_t gray2bin(uint16_t n) {
        uint16_t mask = n;
        while (mask) {
                mask >>= 1;
                n ^= mask;
        }
        return n;
}

void print_phy_regs()
{
        uint32_t cycles_begin, cycles_now, cycles;
        __asm__ volatile ("rdcycle %0" : "=r"(cycles_begin));

        while (1) {
                __asm__ volatile ("rdcycle %0" : "=r"(cycles_now));
                cycles = cycles_now - cycles_begin;
                if (cycles > 48000000) { // per sec.
                        CLS
                        LOC(1,1)
                        GRN print("PHY0_RX_SUCCESS_COUNT:\t");
                        print_hex(gray2bin(reg_phy0_rx_succ_count_gray), 16);
                        RED print("\nPHY0_RX_OVERFLOW_COUNT:\t");
                        print_hex(gray2bin(reg_phy0_rx_OF_count_gray) ,  16);
                        GRN print("\nPHY0_TX_SUCCESS_COUNT:\t");
                        print_hex(gray2bin(reg_phy0_tx_succ_count_gray), 16);
                        RED print("\nPHY0_TX_FAIL_COUNT:\t");
                        print_hex(gray2bin(reg_phy0_tx_fail_count_gray), 16);
                        putchar('\n');

                        GRN print("\nPHY1_RX_SUCCESS_COUNT:\t");
                        print_hex(gray2bin(reg_phy1_rx_succ_count_gray), 16);
                        RED print("\nPHY1_RX_OVERFLOW_COUNT:\t");
                        print_hex(gray2bin(reg_phy1_rx_OF_count_gray) ,  16);
                        GRN print("\nPHY1_TX_SUCCESS_COUNT:\t");
                        print_hex(gray2bin(reg_phy1_tx_succ_count_gray), 16);
                        RED print("\nPHY1_TX_FAIL_COUNT:\t");
                        print_hex(gray2bin(reg_phy1_tx_fail_count_gray), 16);
                        putchar('\n');

                        GRN print("\nPHY2_RX_SUCCESS_COUNT:\t");
                        print_hex(gray2bin(reg_phy2_rx_succ_count_gray), 16);
                        RED print("\nPHY2_RX_OVERFLOW_COUNT:\t");
                        print_hex(gray2bin(reg_phy2_rx_OF_count_gray) ,  16);
                        GRN print("\nPHY2_TX_SUCCESS_COUNT:\t");
                        print_hex(gray2bin(reg_phy2_tx_succ_count_gray), 16);
                        RED print("\nPHY2_TX_FAIL_COUNT:\t");
                        print_hex(gray2bin(reg_phy2_tx_fail_count_gray), 16);
                        putchar('\n');

                        GRN print("\nPHY3_RX_SUCCESS_COUNT:\t");
                        print_hex(gray2bin(reg_phy3_rx_succ_count_gray), 16);
                        RED print("\nPHY3_RX_OVERFLOW_COUNT:\t");
                        print_hex(gray2bin(reg_phy3_rx_OF_count_gray) ,  16);
                        GRN print("\nPHY3_TX_SUCCESS_COUNT:\t");
                        print_hex(gray2bin(reg_phy3_tx_succ_count_gray), 16);
                        RED print("\nPHY3_TX_FAIL_COUNT:\t");
                        print_hex(gray2bin(reg_phy3_tx_fail_count_gray), 16);
                        RES_COL

                        cycles_begin = cycles_now;
                }
        }

        return ;
}

void main()
{
        reg_uart_clkdiv = 104;

        while (getchar_prompt("Press ENTER to continue..\n") != '\r') { /* wait */ }

        print("\n");
        print("  ____  _          ____         ____\n");
        print(" |  _ \\(_) ___ ___/ ___|  ___  / ___|\n");
        print(" | |_) | |/ __/ _ \\___ \\ / _ \\| |\n");
        print(" |  __/| | (_| (_) |__) | (_) | |___\n");
        print(" |_|   |_|\\___\\___/____/ \\___/ \\____|\n");
        print("\n");

        print_hex(HOGEFUGA, 16);

        // print_phy_regs();
}

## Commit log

2022-07-07 add PCB_project
    [pico_router-B_Cu.gbl, pico_router-B_Mask.gbs, pico_router-B_Paste.gbp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]
2022-07-23 CAMのBRAM実装のEG4S20への移植
2022-07-23 MAC_DEC.v 複数入力FIFO, 処理スケジューラの実装
2022-07-24 PHY_TX.vをリファクタリング
2022-07-25 FCSのチェック機能をMAC_DEC.vに実装
2022-07-25 add L2-Switch README.md
2022-07-25 add L2-switch top bench
2022-07-25 file name change : HomemadeSwitch.al -> L2-Switch.al
2022-07-25 合成に成功
2022-08-17 don't use priority encoder & delete backup files
2022-08-18 validate FRAME_FIFO
2022-08-24 add frame_exist flag to FRAME_FIFO.v
2022-08-26 fix FRAME_FIFO.v latency is incorrect
2022-08-26 fix FRAME_FIFO.v latency is invalid
